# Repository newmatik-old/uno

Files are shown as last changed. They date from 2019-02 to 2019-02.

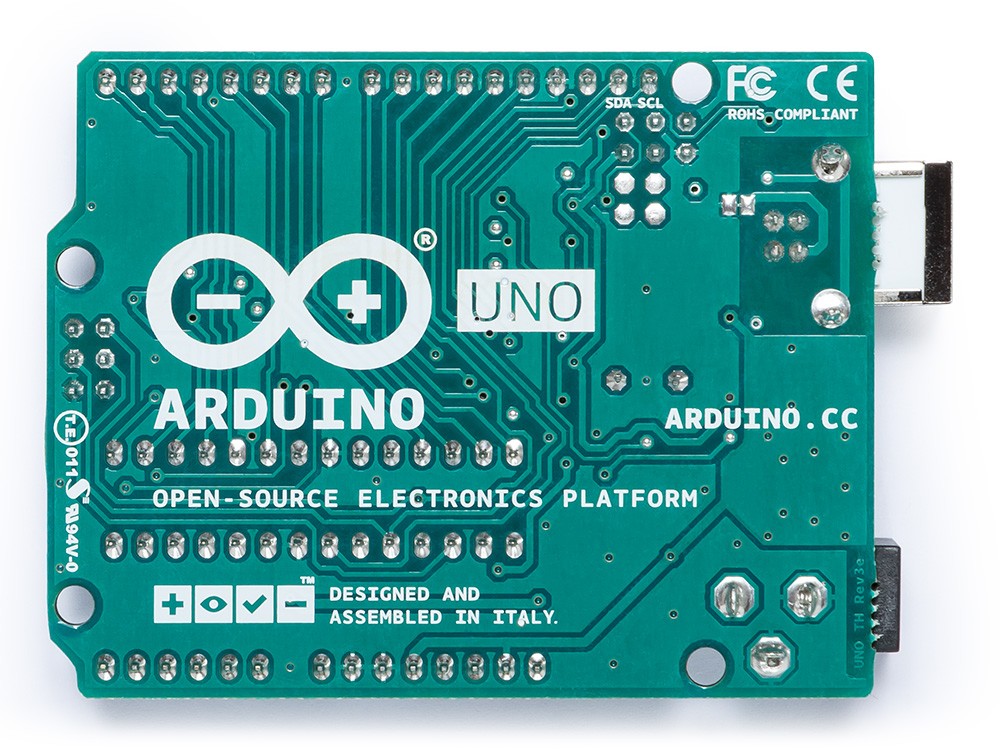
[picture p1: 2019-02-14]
UNO-TH_Rev3e_Image-Bottom.jpg

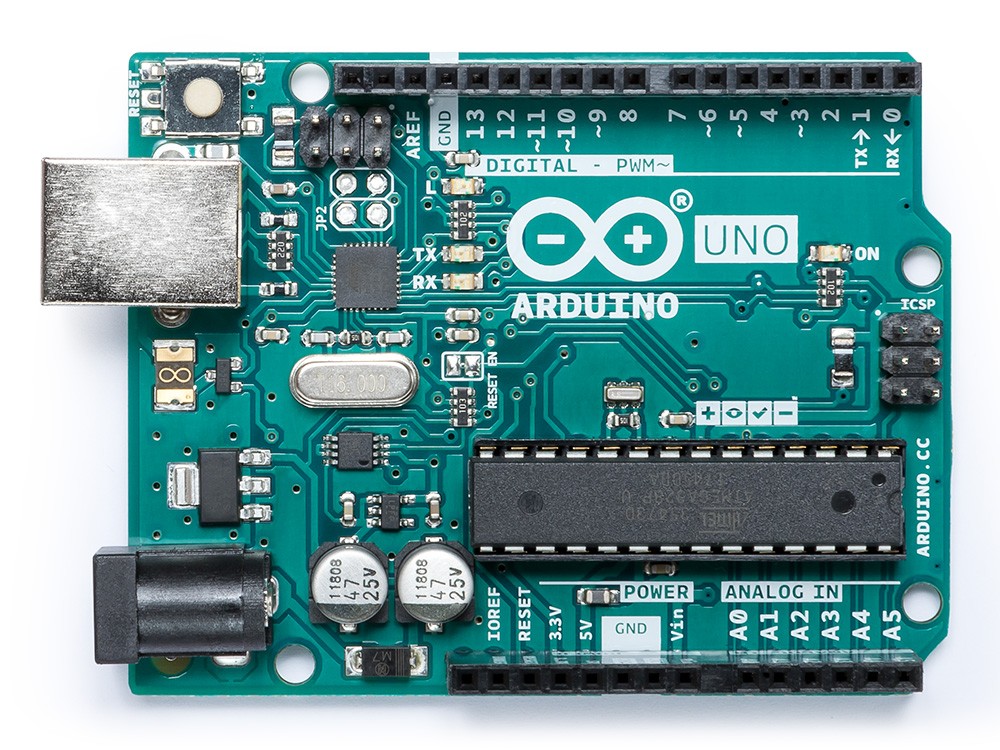
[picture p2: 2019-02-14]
UNO-TH_Rev3e_Image-Top.jpg

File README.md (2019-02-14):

# Uno

This is a complete package of files required to produce your own Arduino Uno. This serves as a demo repository for newmatik.com online PCBA customers to demo-price a project.

This package includes:

- CAD (Eagle board and schematic)
- Gerber Files
- PCB Specification
- Product Images
- Pick and Place File
- 3D Models

## Attributions

- Eagle board file and schematic, product image as well as dxf outlines from Arduino website (https://www.arduino.cc/en/Main/ArduinoBoardUno#documentation)

- Bill of Materials originally from Kitespace (https://github.com/kitspace-forks/arduino-uno)

- Collada and Sketchup 3D models from Trimble 3D Store, created by Engineer-Zero
  (https://3dwarehouse.sketchup.com/model/ee34d0b202060daa949ba13b9dbf2be2/Arduino-Uno?hl=de)

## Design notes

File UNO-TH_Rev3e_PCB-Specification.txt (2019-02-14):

Uno Rev3e PCB Specification

Material: FR4
Thickness: 1.55mm +/-10%
Layers: 2
Dimensions: 68.58mm x 53.34mm
Final Copper Thickness: 35µm (1 OZ)
Surface Finish: Ni/Au (immersion gold)
Solder Mask: green (both sides)
Silk Screen: white (both sides)

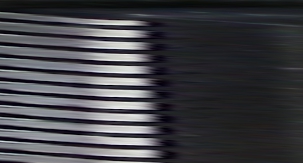
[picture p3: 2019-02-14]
UNO-TH_Rev3e_3D-Model_Collada/model/PB1_1.JPG

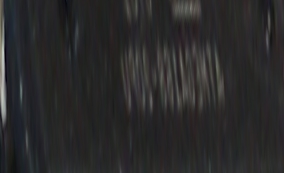
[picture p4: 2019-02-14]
UNO-TH_Rev3e_3D-Model_Collada/model/PB1.JPG

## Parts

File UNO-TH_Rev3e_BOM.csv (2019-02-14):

References | Qty | Description | Manufacturer | Part Number | Manufacturer | Part Number | Manufacturer | Part Number | Manufacturer | Part Number | Digikey | Mouser | RS | Newark | Farnell
C9, C11 | 2 | 22pF capacitor ceramic | Johanson | 500R14N220JV4T | Multicomp | MC0603N220J500CT | Vishay Vitramon | VJ0603A220KXQPW1BC | Kemet | C0603C220J5GACTU | 709-1143-1-ND | VJ0603A220KXQPW1BC | 2644501 | 06R5149 | 1759057
C1, C2, C4, C5, C6, C7 | 6 | 100nF capacitor ceramic | Yageo | CC0603KRX7R9BB104 | Kemet | C0603C104K5RACTU | Murata | GRM188R71H104KA93D |  |  | 490-1519-1-ND | GRM188R71H104KA93D | 7235676 | 38K1670 | 8820023
C3, C8 | 2 | 1uF capacitor ceramic 6.3V | Murata | GRM188R60J105KA01D | TDK | C1608X5R1A105MT | AVX | 06036D105KAT2A |  |  | 490-1550-1-ND | GRM188R60J105KA01D | 6242682 | 84K8390 | 9527699
PC1, PC2 | 2 | 47uF electrolytic capacitor SMT | United Chemi-Con | EMVA250ADA470MF55G | Cornell Dubilier | AVE476M50X16T-F | Nichicon | UWT1V470MCL1GS |  |  | 493-2202-1-ND | AVE476M50X16TF | 7567973 | 96W2438 | 1668297
X1 | 1 | 2.1mm DC power jack | CUI | PJ-102A | RS Pro | 487-848 | Lumberg | NEB 21 R | Cliff Electronic Components | DC10A | CP-102A-ND | PJ102A | 487848 | 20T2054 | 1217037
X2 | 1 | USB type B connector right-angle | On Shore Technology | USB-B1HSW6 | On Shore Technology | USB-B1HSB6 | TE Connectiviy | 4-1734376-7 |  |  | ED2983-ND | 571417343767 | 5298218 | 41J2935 | 1076665
JP2 | 1 | Pin header 0.1” 2x2 | FCI | 67997-404HLF | Harwin | M20-9990445 |  |  |  |  | 609-3242-ND | 67997404HLF | 8632753 | 33M7902 | 1022250
ICSP, ICSP1 | 2 | Pin header 0.1” 2x3 | FCI | 67996-406HLF | Harwin | M20-9980346 |  |  |  |  | 609-3218-ND | 67996406HLF | 7457046 | 20M2191 | 1022231
AD | 1 | Socket strip 0.1” 1x6 | Harwin | M20-7820646 | TE Connectivity / AMP | 5-534237-4 | Samtec | SSQ-106-01-G-S |  |  | A32907-ND | 55342374 | 7926681 | 62M8851 | 1668297
IOL, POWER | 2 | Socket strip 0.1” 1x8 | 3M | 960108-6202-AR | Harwin | M20-7820842 | Samtec | BCS-108-L-S-TE |  |  | 952-1823-ND | M207820842 | 8277734 | 62R6734 | 1667474
IOH | 1 | Socket strip 0.1” 1x10 | Harwin | M20-7821046 | TE Connectivity | 5-534237-8 | Samtec | SSQ-110-01-G-S |  |  | A32910-ND | 55342378 | 7973233 | 52K3746 | 1668307
Y1 | 1 | 16MHz 18pF | CTS Components | ATS16B | Abracon | ABL-16.000MHZ-B2 |  |  |  |  | CTX1085-ND | ABL16.000MHZB2 | 7031818 | 13J1628 | 2449511
D2, D3 | 2 | Switching diode | Bourns | CD1206-S01575 |  |  |  |  |  |  | CD1206-S01575CT-ND | CD1206S01575 | 7734514 | 09J8040 | 2211947
D1 | 1 | Switching diode | Diodes Inc. | S2M-13-F | Fairchild Semiconductor | S2J |  |  |  |  | S2JFSCT-ND | 512S2J | 8032002 | 58K2394 | 2454585
L1 | 1 | Ferrite 50mOhm@DC / 220ohm@100MHz | Murata | BLM21PG221SN1D | Iqd Frequency Products | LFXTAL024944 |  |  |  |  | 490-1054-1-ND | BLM21PG221SN1D | 7241532 | 73M9167 | 1515661
F1 | 1 | Fuse 500mA 15V | Bourns | MF-MSMF050-2 |  |  |  |  |  |  | MF-MSMF050-2CT-ND | MFMSMF0502 | 6478156 | 02J2718 | 9350314
U3 | 1 | ATmega16U2 16kB FLASH | Atmel | ATMEGA16U2-MUR | Atmel | ATMEGA16U2-MU |  |  |  |  | ATMEGA16U2-MURCT-ND | ATMEGA16U2MU | 7153791 | 68T2601 | 1841607
ZU4 | 1 | ATmega328P | Atmel | ATMEGA328P-PU |  |  |  |  |  |  | ATMEGA328P-PU-ND | ATMEGA328PPU | 6962260 | 68T2944 | 1715487
U5 | 1 | Dual op-amp RRO | Texas Instruments | LMV358IDGKR | Microchip | MCP6002-E/MS | Microchip | MCP6002T-I/MS |  |  | MCP6002-E/MS-ND | MCP6002E/MS | 7240444 | 72C4273 | 1840886
U2 | 1 | 150mA 3.3V LDO | Texas Instruments | LP2985-33DBVR |  |  |  |  |  |  | 296-18476-1-ND | LP298533DBVR | 5360868 | 43J9346 | 2395925
U1 | 1 | 1A 5V LDO | ON Semiconductor | NCP1117ST50T3G |  |  |  |  |  |  | NCP1117ST50T3GOSCT-ND | NCP1117ST50T3G | 8022130 | 71J6563 | 2112617
ON | 1 | LED green | Osram | LGR971-KN-1-0-20-R18 | Dialight | 598-8160-107F |  |  |  |  | 350-2043-1-ND | 5988160107F | 6921271 | 75R0586 | 1465994
L, RX, TX | 3 | LED yellow | Lite-On | LTST-C171KSKT | Kingbright | APT2012YC |  |  |  |  | 754-1135-1-ND | APT2012YC | 6920950 | 75R0620 | 1465994
RN3 | 1 | 22ohm 4-resistor series array | Bourns | CAY16-220J4LF | Yageo | YC164-JR-0722RL |  |  |  |  | CAY16-220J4LFCT-ND | CAY16220J4LF | 5225620 | 68R0343 | 1770127
RN2, RN4 | 2 | 1k 4-resistor series array | Bourns | CAY16-102J4LF |  |  |  |  |  |  | CAY16-102J4LFCT-ND | CAY16102J4LF | 5225579 | 96M0890 | 1770133
RN1 | 1 | 10k 4-resistor series array | Bourns | CAY16-103J4LF |  |  |  |  |  |  | CAY16-103J4LFCT-ND | CAY16103J4LF | 5225585 | 02J1097 | 1770137
R1, R2 | 2 | 1M resistor 1/10W | Panasonic | ERJ-3GEYJ105V | Bourns | CR0603-JW-105GLF | Vishay | CRCW06031M00FKEA |  |  | CR0603-JW-105GLFCT-ND | CR0603JW105GLF | 7325668 | 32K2615 | 2008367
Y2 | 1 | 16MHz resonator with built-in caps | Murata | CSTCE16M0V53-R0 |  |  |  |  |  |  | 490-1198-1-ND | CSTCE16M0V53R0 | 7926524 | 87X8657 | 2443265
RESET | 1 | Tactile switch | TE Connectivity / Alcoswitch | FSM1LPATR | TE Connectivity | FSM1LP |  |  |  |  | 450-1760-1-ND | 114375658 | 9098028 | 14H0904 | 1813691
T1 | 1 | 20V P-type MOSFET | Fairchild Semiconductor | FDN340P |  |  |  |  |  |  | FDN340PCT-ND | FDN340P | 2132676 | 58K8841 | 9846310
Z1, Z2 | 2 | Low-capacitance varistor 5V WV | Bourns | CG0603MLC-05E | AVX | VCUG060050L1DP |  |  |  |  | CG0603MLC-05ECT-ND | CG0603MLC05E | 8518256 | 97M3815 | 1838966

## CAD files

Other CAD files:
UNO-TH_Rev3e_Outlines-CAD.dxf

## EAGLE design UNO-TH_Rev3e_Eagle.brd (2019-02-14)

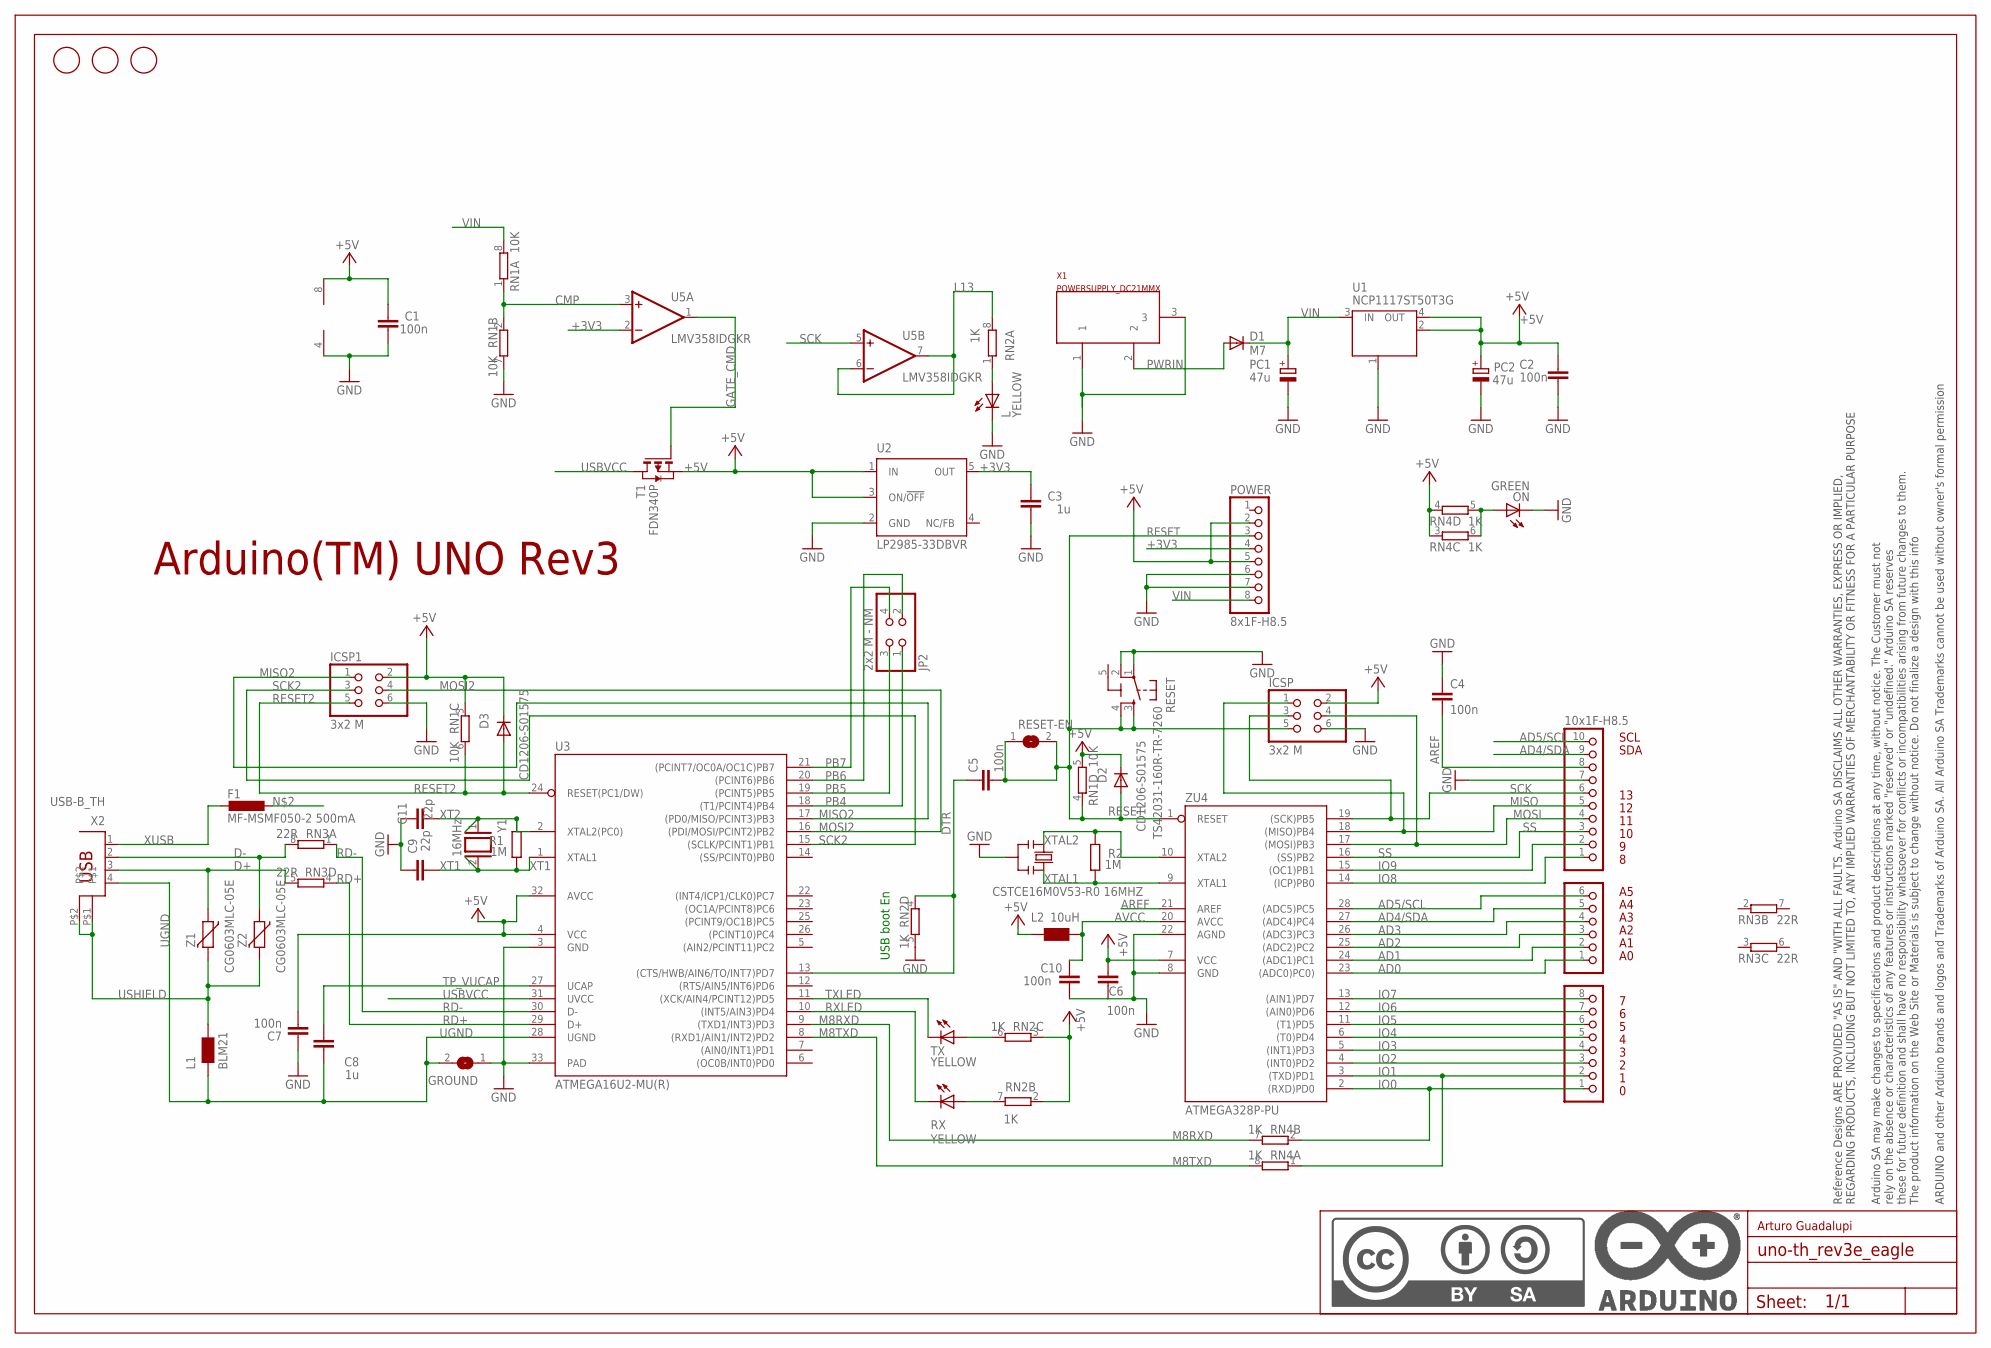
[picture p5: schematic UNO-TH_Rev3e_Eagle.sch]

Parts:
AD: 6x1F-H8.5; 1X06
C1, C2, C4, C5, C6, C7, C10: 100n; C0603-ROUND
C3, C8: 1u; C0603-ROUND
C9, C11: 22p; C0603-ROUND
D1: M7; SMB
D2, D3: CD1206-S01575; MINIMELF
F1: MF-MSMF050-2 500mA; L1812
FD1, FD2, FD3: FIDUCIALMOUNT; FIDUCIA-MOUNT
FRAME1: DNP; FRAME
GROUND: SJ
ICSP, ICSP1: 3x2 M; 2X03
IOH: 10x1F-H8.5; 1X10
IOL: 8x1F-H8.5; 1X08
JP2: 2x2 M - NM; 2X02
L: YELLOW; CHIP-LED0805
L1: BLM21; 0805
L2: 10uH; 0805
ON: GREEN; CHIP-LED0805
PC1, PC2: 47u; PANASONIC_D
POWER: 8x1F-H8.5; 1X08
R1, R2: 1M; R0603-ROUND
RESET: TS42031-160R-TR-7260; TS42
RESET-EN: SJ
RN1: 10K; CAY16
RN2, RN4: 1K; CAY16
RN3: 22R; CAY16
RX: YELLOW; CHIP-LED0805
T1: FDN340P; SOT-23
TX: YELLOW; CHIP-LED0805
U1: NCP1117ST50T3G; SOT223
U2: LP2985-33DBVR; SOT23-DBV
U3: ATMEGA16U2-MU(R); MLF32
U5: LMV358IDGKR; MSOP08
X1: POWERSUPPLY_DC21MMX; POWERSUPPLY_DC-21MM
X2: USB-B_TH; PN61729
Y1: 16MHz; QS
Y2: CSTCE16M0V53-R0 16MHZ; RESONATOR
Z1, Z2: CG0603MLC-05E; CT/CN0603
ZU4: ATMEGA328P-PU; DIL28-3

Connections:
5-GND: RESET.5 (5-GND)
+3V3: C3.2, POWER.4, U2.5 (OUT), U5.2 (-IN)
+5V: C1.2, C2.2, C6.2, C7.1, D2.C, D3.C, ICSP.2, ICSP1.2, L2.1, PC2.+, POWER.2, POWER.5, RN1.3 (1), RN1.5 (2), RN2.2 (1), RN2.3 (1), RN4.3 (1), RN4.4 (1), T1.2 (S), U1.2 (OUT), U1.4 (OUT), U2.1 (IN), U2.3 (ON/!OFF), U3.4 (VCC), U3.32 (AVCC), U5.8 (V+), ZU4.7 (VCC)
AD0: AD.1, ZU4.23 ((ADC0)PC0))
AD1: AD.2, ZU4.24 ((ADC1)PC1)
AD2: AD.3, ZU4.25 ((ADC2)PC2)
AD3: AD.4, ZU4.26 ((ADC3)PC3)
AD4/SDA: AD.5, IOH.9, ZU4.27 ((ADC4)PC4)
AD5/SCL: AD.6, IOH.10, ZU4.28 ((ADC5)PC5)
AREF: C4.2, IOH.8, ZU4.21 (AREF)
AVCC: C10.2, L2.2, ZU4.20 (AVCC)
CMP: RN1.1, RN1.2 (1), U5.3 (+IN)
D+: RN3.5 (2), X2.3, Z1.1
D-: RN3.8 (2), X2.2, Z2.1
DTR: C5.1, RN2.4 (1), U3.13 ((CTS/HWB/AIN6/TO/INT7)PD7)
GATE_CMD: T1.3 (G), U5.1 (OUT)
GND: C1.1, C2.1, C3.1, C4.1, C6.1, C7.2, C9.2, C10.1, C11.2, GROUND.1, ICSP.6, ICSP1.6, IOH.7, L.C, ON.C, PC1.-, PC2.-, POWER.6, POWER.7, RESET.1, RESET.2, RN1.7 (2), RN2.5 (2), U1.1 (GND/ADJ), U2.2 (GND), U3.3 (GND), U3.33 (PAD), U5.4 (V-), X1.1, X1.3, Y2.2, ZU4.8 (GND), ZU4.22 (AGND)
IO0: IOL.1, RN4.2 (1), ZU4.2 ((RXD)PD0)
IO1: IOL.2, RN4.1, ZU4.3 ((TXD)PD1)
IO2: IOL.3, ZU4.4 ((INT0)PD2)
IO3: IOL.4, ZU4.5 ((INT1)PD3)
IO4: IOL.5, ZU4.6 ((T0)PD4)
IO5: IOL.6, ZU4.11 ((T1)PD5)
IO6: IOL.7, ZU4.12 ((AIN0)PD6)
IO7: IOL.8, ZU4.13 ((AIN1)PD7)
IO8: IOH.1, ZU4.14 ((ICP)PB0)
IO9: IOH.2, ZU4.15 ((OC1)PB1)
L13: RN2.8 (2), U5.6 (-IN), U5.7 (OUT)
M8RXD: RN4.7 (2), U3.9 ((TXD1/INT3)PD3)
M8TXD: RN4.8 (2), U3.8 ((RXD1/AIN1/INT2)PD2)
MISO: ICSP.1, IOH.5, ZU4.18 ((MISO)PB4)
MISO2: ICSP1.1, U3.17 ((PD0/MISO/PCINT3)PB3)
MOSI: ICSP.4, IOH.4, ZU4.17 ((MOSI)PB3)
MOSI2: ICSP1.4, U3.16 ((PDI/MOSI/PCINT2)PB2)
unnamed: L.A, RN2.1
unnamed: ON.A, RN4.5 (2), RN4.6 (2)
unnamed: RN2.7 (2), RX.A
unnamed: RN2.6 (2), TX.A
PB4: JP2.1, U3.18 ((T1/PCINT4)PB4)
PB5: JP2.3, U3.19 ((PCINT5)PB5)
PB6: JP2.2, U3.20 ((PCINT6)PB6)
PB7: JP2.4, U3.21 ((PCINT7/OC0A/OC1C)PB7)
PWRIN: D1.A, X1.2
RD+: RN3.4 (1), U3.29 (D+)
RD-: RN3.1, U3.30 (D-)
RESET: C5.2, D2.A, ICSP.5, POWER.3, RESET.3, RESET.4, RESET-EN.1, RESET-EN.2, RN1.4 (1), ZU4.1 (RESET)
RESET2: D3.A, ICSP1.5, RN1.6 (2), U3.24 (RESET(PC1/DW))
RXLED: RX.C, U3.10 ((INT5/AIN3)PD4)
SCK: ICSP.3, IOH.6, U5.5 (+IN), ZU4.19 ((SCK)PB5)
SCK2: ICSP1.3, U3.15 ((SCLK/PCINT1)PB1)
SS: IOH.3, ZU4.16 ((SS)PB2)
TP_VUCAP: C8.1, U3.27 (UCAP)
TXLED: TX.C, U3.11 ((XCK/AIN4/PCINT12)PD5)
UGND: C8.2, GROUND.2, L1.1, U3.28 (UGND), X2.4
USBVCC: T1.1 (D), U3.31 (UVCC)
USHIELD: L1.2, X2.P$1, X2.P$2, Z1.2, Z2.2
VIN: D1.C, PC1.+, POWER.8, RN1.8 (2), U1.3 (IN)
XT1: C9.1, R1.1, U3.1 (XTAL1), Y1.2
XT2: C11.1, R1.2, U3.2 (XTAL2(PC0)), Y1.1
XTAL1: R2.1, Y2.3, ZU4.9 (XTAL1)
XTAL2: R2.2, Y2.1, ZU4.10 (XTAL2)
XUSB: F1.2, X2.1

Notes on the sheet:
Arduino(TM) UNO Rev3
USB boot En
SDA
SCL
Arturo Guadalupi

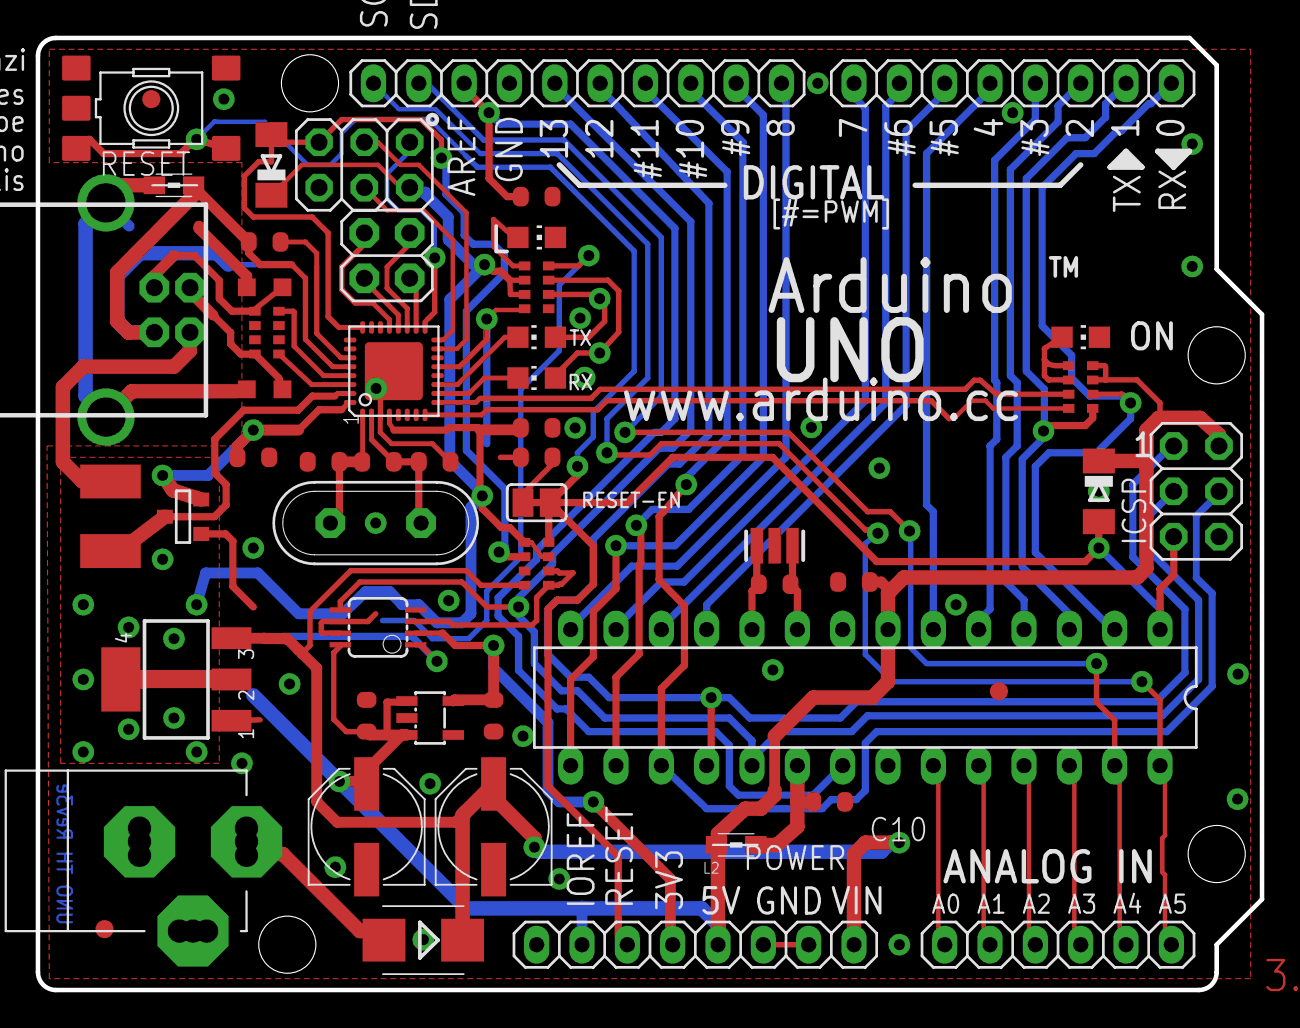
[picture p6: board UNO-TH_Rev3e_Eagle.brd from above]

Board: 2 copper layers, 68.6 x 53.3 mm, 55 parts (1 on the bottom side), 61 nets.

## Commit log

2019-02-14 Add BOM
    [UNO-TH_Rev3e_BOM.csv]
2019-02-14 Add PCB Specification
2019-02-14 Add Readme and CAD Outlines
    [UNO-TH_Rev3e_Outlines-CAD.dxf]
2019-03-20 Change Gerber Outline to .gm1
    [outline.gm1]

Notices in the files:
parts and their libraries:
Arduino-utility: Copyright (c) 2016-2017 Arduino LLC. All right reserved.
